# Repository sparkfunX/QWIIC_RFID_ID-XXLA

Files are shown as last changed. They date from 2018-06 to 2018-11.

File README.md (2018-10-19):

SparkX Qwiic RFID ID-XXLA
========================================

SparkX Qwiic RFID 

[*SparX Qwiic RFID (SPX-14867)*](https://www.sparkfun.com/products/14867)

The Qwiic RFID ID-XXLA is a simple board that pairs with the ID-3LA, ID-12LA, ID-20LA, RFID modules. Included with the product is the ID-12LA and three RFID 125Khz cards as a full kit to get you started integrating an I2C RFID solution into your project. Utilizing the onboard ATtiny84A, the Qwiic RFID takes the six byte ID tag of your 125Khz RFID card, attaches a time stamp to it, and puts it onto a stack that holds up to 20 unique RFID scans at any given time. This information is easy to get at with some simple I2C commands and we’ve included some example code that shows you just how to do it using the broken out interrupt pin. We’ve also broken out two antennae pins that should only be used with the smaller ID-3LA.

The Qwiic RFID has a buzzer and LED that indicates that card has been scanned. We’ve included a jumper to disconnect the buzzer, a jumper for the I2C pull-up resistors, an interrupt jumper, and finally an address jumper. The Qwiic RFID comes fully decked out in Qwiic connectors, no need to solder a thing, just plug it in and start scanning!

We do not plan to regularly produce SparkX products so get them while they’re hot!

Repository Contents
-------------------

* **/Examples** - A number of examples to show how to read buttons with time, change the I2C address and scan for I2C devices
* **/Firmware** - The core sketch that runs Qwiic RFID ID-XXLA
* **/Hardware** - Eagle design files (.brd, .sch)

License Information
-------------------

This product is _**open source**_! 

Please review the LICENSE.md file for license information. 

If you have any questions or concerns on licensing, please contact techsupport@sparkfun.com.

Please use, reuse, and modify these files as you see fit. Please maintain attribution to SparkFun Electronics and release any derivative under the same license.

Distributed as-is; no warranty is given.

- Your friends at SparkFun.

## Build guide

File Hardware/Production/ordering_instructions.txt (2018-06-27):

panel size, 91x107mm
PCB thickness, 1.6mm
number of layers, 2
soldermask color, Black
silkscreen color, White
oz copper, 1oz
finish, HASL lead free
stencils, top+bottom
pcs per panel, 9

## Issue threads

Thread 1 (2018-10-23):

Problem reading using an ESP32Thing

f34rdotcom, 2018-10-23:
I have been unable to read back from the device. I have multiple devices on an i2c bus and other devices do read so I am leaning towards an issue in this firmware not being compatible with esp-idf i2c driver.

When I write to its address 0x7d it does report an ACK that and so my i2c scanner does detect the device successfully. If however I try and read by 10 bytes from the device it end up with a timeout from the i2c driver on the esp32. It also seems to take a long time for the ATINY to ACK the address byte when reading. If I write to the address the ATINY does not delay the ACK.

I have disabled PULL UP's on all the devices on my i2c bus and turn on pullup on the GPIO pins on the ESP32

It is not clear what firmware is on the QWIIC_RFID_ID but it was within the past few weeks purchased from sparkfun.

Any help/suggestions appreciated.

```
i2c_config_t conf;
conf.mode = I2C_MODE_MASTER;
conf.sda_io_num = GPIO_NUM_4;
conf.scl_io_num = GPIO_NUM_2;
conf.sda_pullup_en = GPIO_PULLUP_ENABLE;
conf.scl_pullup_en = GPIO_PULLUP_ENABLE;
conf.master.clk_speed = speed;
ESP_ERROR_CHECK(i2c_param_config(I2C_NUM_0, &conf));
ESP_ERROR_CHECK(i2c_driver_install(I2C_NUM_0, I2C_MODE_MASTER, 0, 0, 0));

uint8_t temp[32];
i2c_cmd_handle_t cmd = i2c_cmd_link_create();
i2c_master_start(cmd);
i2c_master_write_byte(cmd, (0x7d << 1) | I2C_MASTER_READ, true);
ESP_ERROR_CHECK(i2c_master_read(cmd, temp, 9, ACK_VAL));
ESP_ERROR_CHECK(i2c_master_read_byte(cmd, temp+9, NACK_VAL));
i2c_master_stop(cmd);
espRc = i2c_master_cmd_begin(I2C_NUM_0, cmd, 100/portTICK_PERIOD_MS);
if (espRc == ESP_OK) {
  printf("OK);
} else {
  printf("FAIL");
}
i2c_cmd_link_delete(cmd);

```
The resulting capture.
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

edspark, 2018-10-24:
Hmmm...nothing comes to mind off the top of my head. I'll take a gander at this today and hopefully find an answer for you.

edspark, 2018-10-24:
I hooked up my a Sparkfun ESP32 Thing to my Qwiic RFID and was able to read back from two separate tags using pins 21/22 as SDA/SCL respectively with no other devices attached:
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

My first thought is that there's some sort of cold joint on the UART pin from the RFID reader to the product. I did however test each one of the boards personally, but it is possible that something got bumped in transit or through use.  Below is an image of the header for the RFID module with the pad for the UART pin circled in blue(pin 9):
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

Let me know if there's anything else I can help with.

f34rdotcom, 2018-10-24:
The problem I am seeing is on the i2c bus portion from the ATTINY85 chip not the UART pins. As best I can describe the ATTINY85 is not pulling down the SDA line after the 8th bit to indicate it received the READ command with address.

f34rdotcom, 2018-11-01:
Just an update.

I am able to read the bytes using an ESP32Thing provided I set the i2c timeout after installing the i2c driver. The default value is 6400.
  `i2c_set_timeout(I2C_NUM_0, 32000);`

This fixes the "clock stretching" that is happening from the ATTINY85 board. I am however still see many random bad responses with NAK errors and AFAIK I have no way of detecting if a message had NAK errors. I end up with a successful read but the data is full of 0xff bytes. These issues seem very specific to esp-idf so I am going to close this. If you have some ability to help me confirm and help determine how to fix this any help would be appreciated.

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

RFID:80ffffffffffffffffff
I (5539912) MYI2CSENS: myi2c-rfid 4294967295,42949672
RFID:000000000000000001c1
I (5540412) MYI2CSENS: myi2c-rfid 449,0
RFID:000000000000000001c1
I (5540912) MYI2CSENS: myi2c-rfid 449,0
RFID:000000000000000001c1
I (5541412) MYI2CSENS: myi2c-rfid 449,0
RFID:000000000000000001c1
I (5541912) MYI2CSENS: myi2c-rfid 449,0
RFID:0000000000007fffffff
I (5542412) MYI2CSENS: myi2c-rfid 2147483647,0

edspark, 2018-11-30:
I'm going to close this for now @f34rdotcom. If you discover something please feel free to open it back up.

Closed 2018-11-30.

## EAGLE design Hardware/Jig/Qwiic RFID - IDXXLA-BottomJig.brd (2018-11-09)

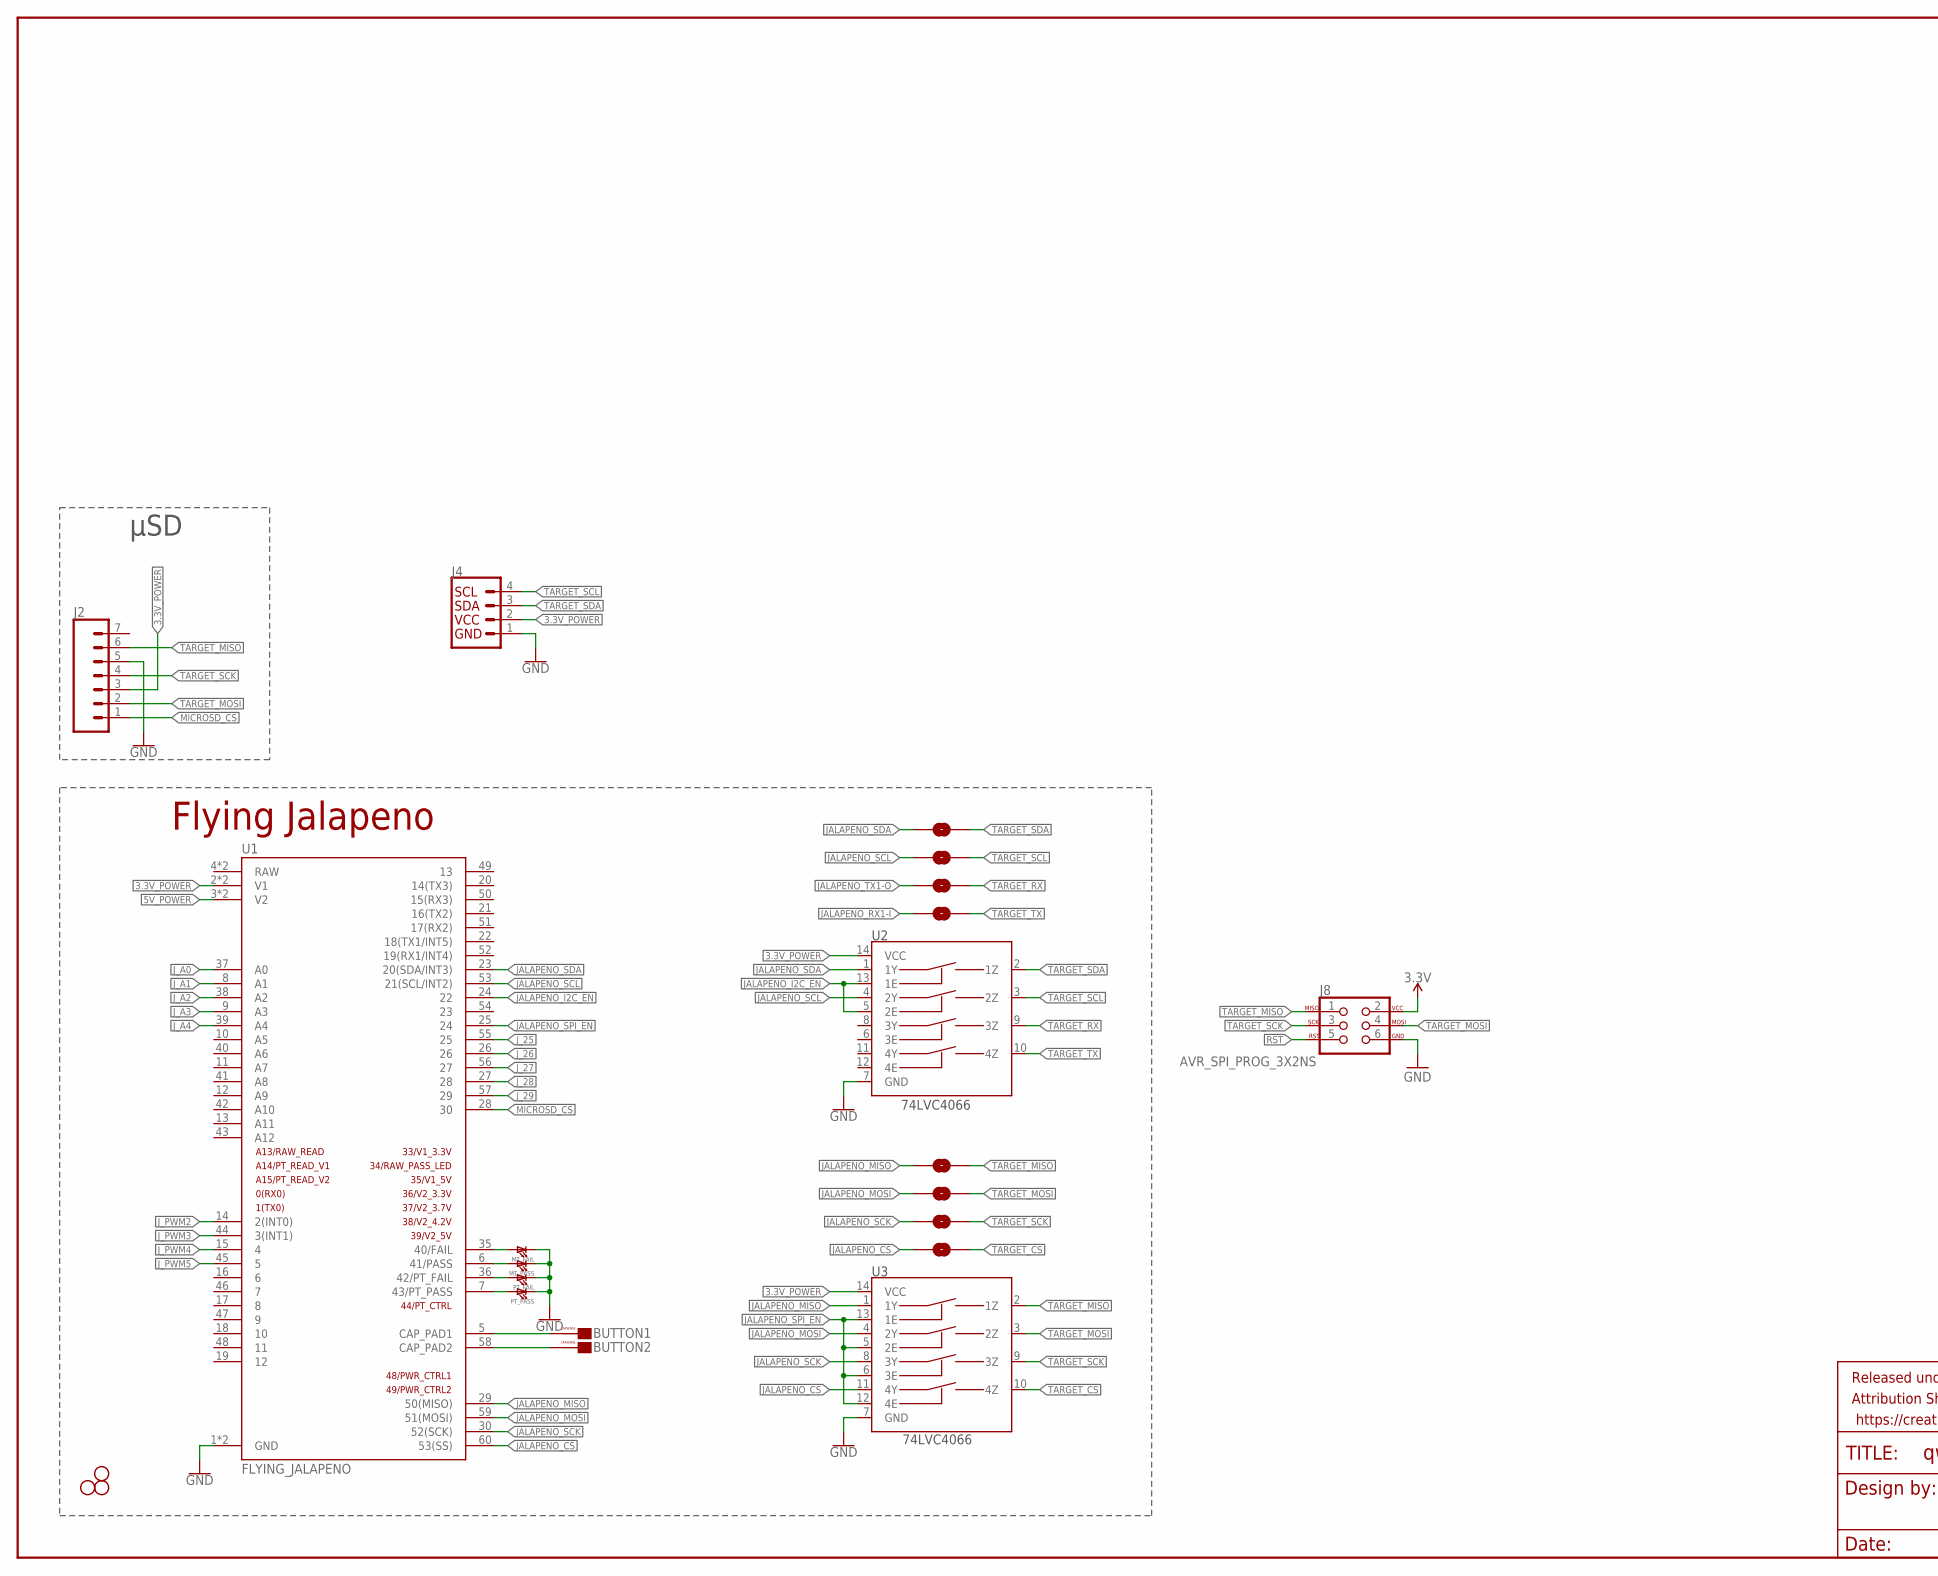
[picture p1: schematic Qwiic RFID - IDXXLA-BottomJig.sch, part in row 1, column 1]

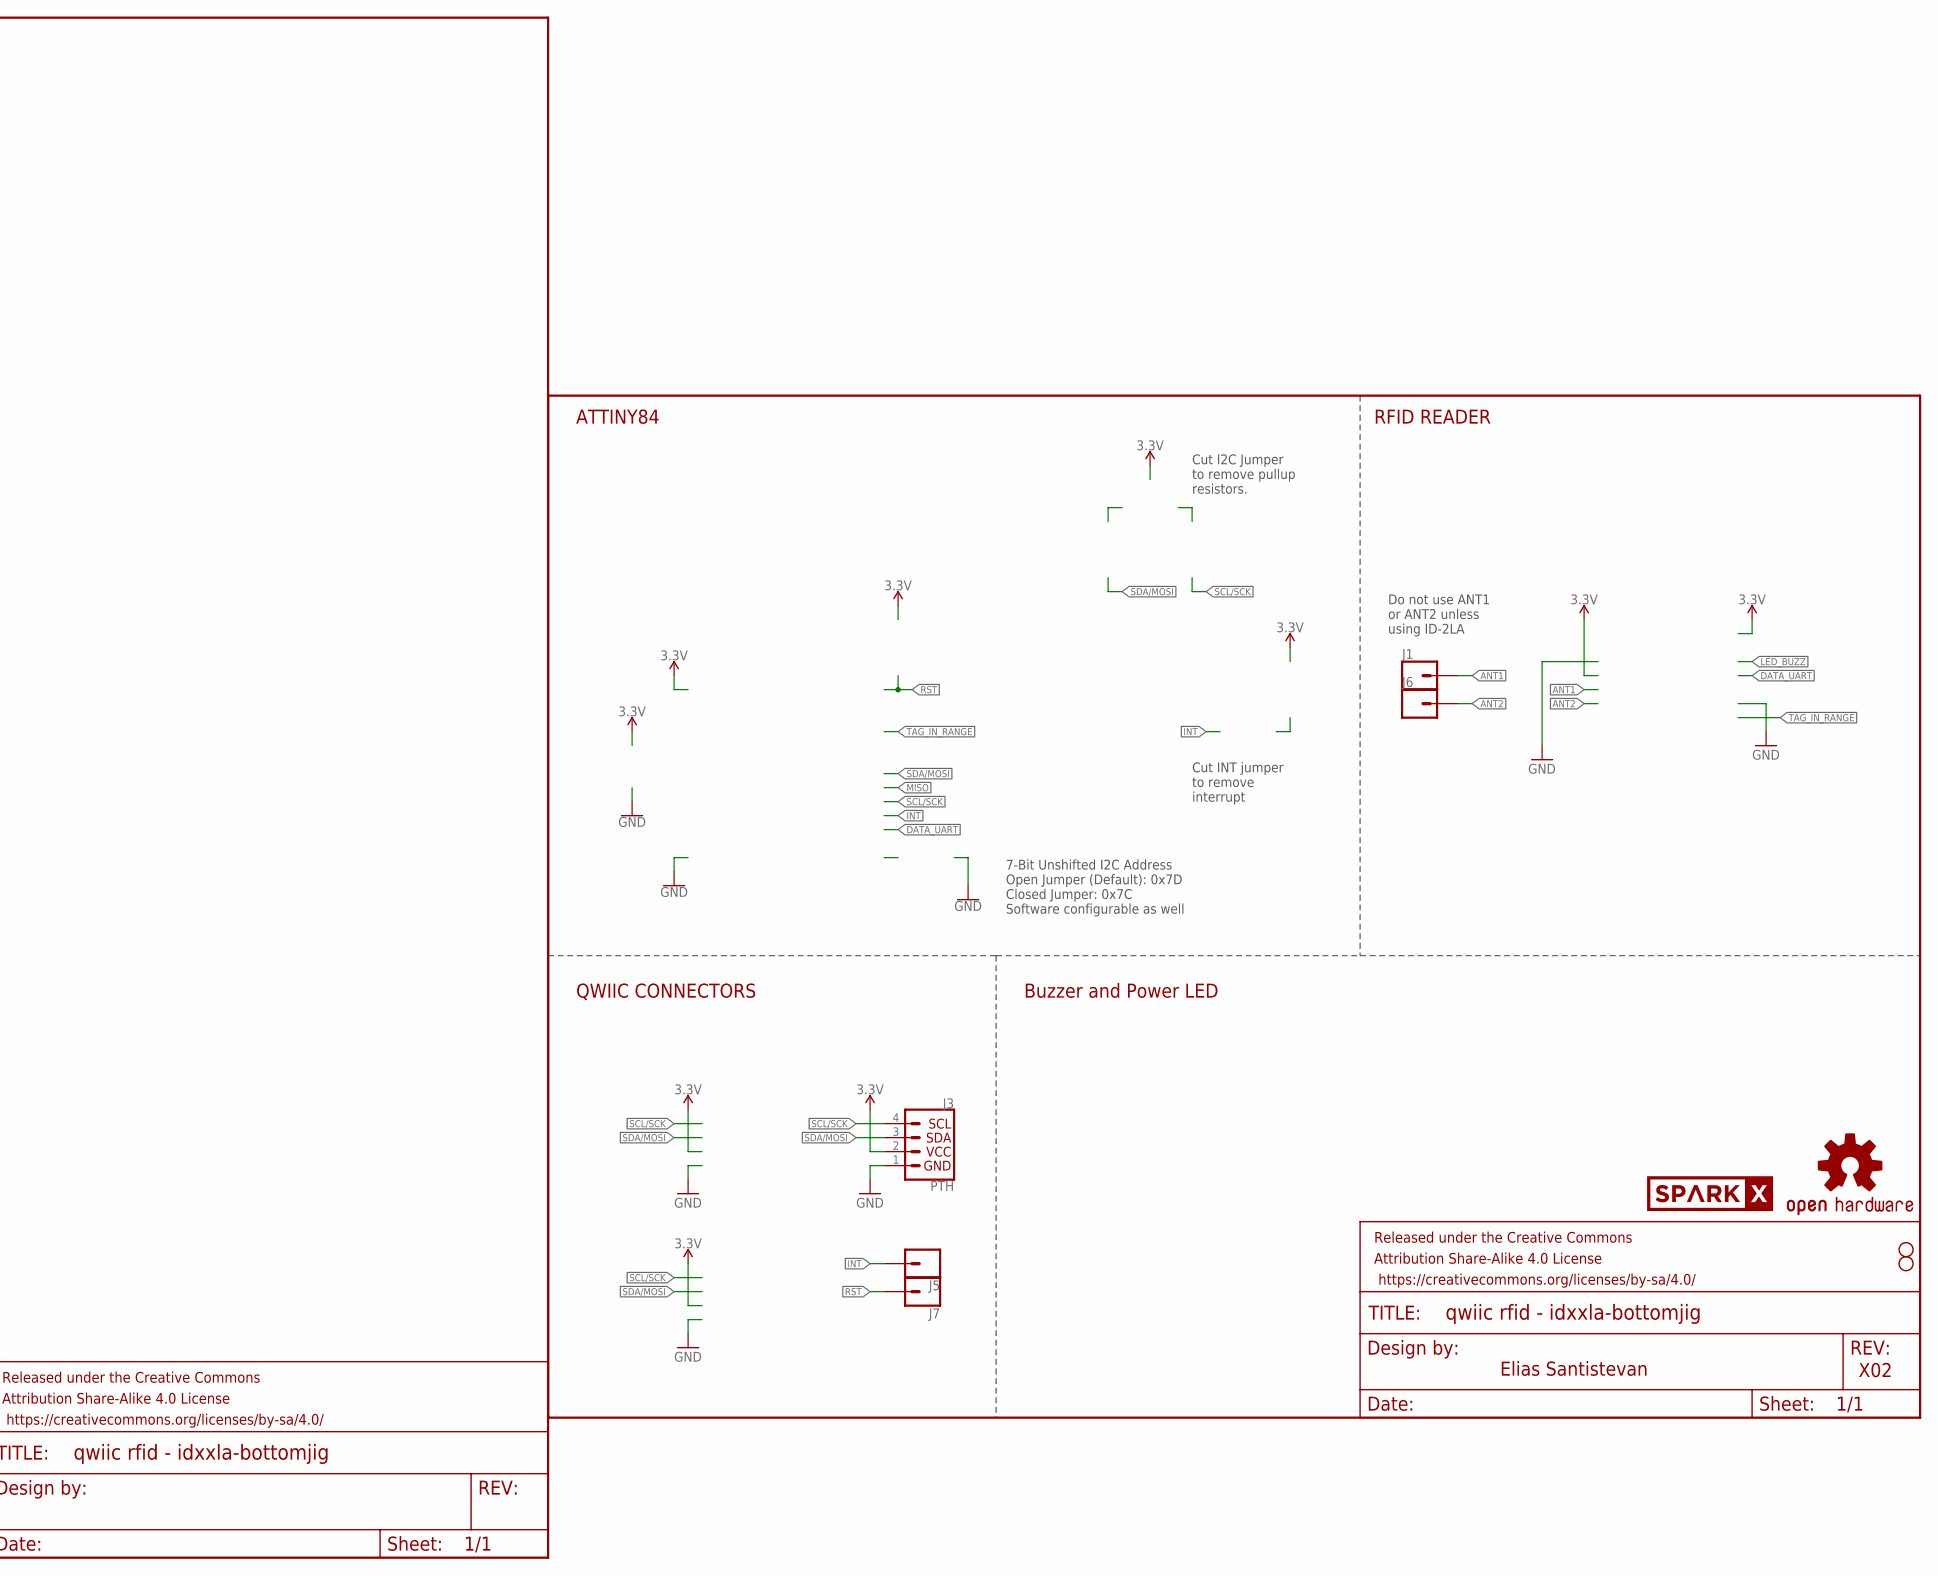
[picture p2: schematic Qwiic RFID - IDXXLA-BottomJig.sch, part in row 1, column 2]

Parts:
BUTTON1, BUTTON2: CAPSENSE_BUTTON_PAD_ONLY; CAPSENSE_BUTTON_PADS_ONLY
FRAME1: FRAME-LETTER; CREATIVE_COMMONS
FRAME2: FRAME-LEDGER; CREATIVE_COMMONS
H1, H3, H4: STAND-OFF
J1, J5, J6, J7: CONN_01PTH_NO_SILK_YES_STOP; 1X01_NO_SILK
J2: CONN_07; 1X07
J3: PTH; 1X04_NO_SILK
J4: QWIIC_CONNECTORJS-1MM; 1X04_1MM_RA
J8: AVR_SPI_PROG_3X2NS; 2X3-NS
JP3, JP4: STAND-OFF
J_SCL, J_SCL1, J_SCL2, J_SCL3, J_SCL4, J_SCL5: JUMPER-SMT_2_NO_NO-SILK; SMT-JUMPER_2_NO_NO-SILK
J_SDA, J_SDA1: JUMPER-SMT_2_NO_NO-SILK; SMT-JUMPER_2_NO_NO-SILK
LOGO1: OSHW-LOGOMINI; OSHW-LOGO-MINI
MT_FAIL: LED1206; LED-1206
MT_PASS: LED1206; LED-1206
PT_FAIL: LED1206; LED-1206
PT_PASS: LED1206; LED-1206
U1: FLYING_JALAPENO; FLYING_JALAPENO_V3_M
U2, U3: 74LVC4066; SO14
U$4: SPARKX-LOGO3; SPARKX-SMALL

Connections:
3.3V: J3.2 (VCC), J8.2
3.3V_POWER: J2.3, J4.2, U1.2 (V1), U1.32 (V1), U2.14 (VCC), U3.14 (VCC)
5V_POWER: U1.3 (V2), U1.33 (V2)
!INT: J5.1
!RST: J7.1, J8.5
ANT1: J1.1
ANT2: J6.1
BUTTON1: BUTTON1.CAPSENSE_PAD, U1.5 (CAP_PAD1)
BUTTON2: BUTTON2.CAPSENSE_PAD, U1.58 (CAP_PAD2)
GND: J2.5, J3.1 (GND), J4.1, J8.6, MT_FAIL.C, MT_PASS.C, PT_FAIL.C, PT_PASS.C, U1.1 (GND), U1.31 (GND), U2.7 (GND), U3.7 (GND)
JALAPENO_CS: J_SDA1.1, U1.60 (53(SS)), U3.11 (4Y)
JALAPENO_I2C_EN: U1.24 (22), U2.5 (2E), U2.13 (1E)
JALAPENO_MISO: J_SCL5.1, U1.29 (50(MISO)), U3.1 (1Y)
JALAPENO_MOSI: J_SCL3.1, U1.59 (51(MOSI)), U3.4 (2Y)
JALAPENO_RX1-I: J_SDA.1
JALAPENO_SCK: J_SCL4.1, U1.30 (52(SCK)), U3.8 (3Y)
JALAPENO_SCL: J_SCL.1, U1.53 (21(SCL/INT2)), U2.4 (2Y)
JALAPENO_SDA: J_SCL2.1, U1.23 (20(SDA/INT3)), U2.1 (1Y)
JALAPENO_SPI_EN: U1.25 (24), U3.5 (2E), U3.6 (3E), U3.12 (4E), U3.13 (1E)
JALAPENO_TX1-O: J_SCL1.1
J_25: U1.55 (25)
J_26: U1.26
J_27: U1.56 (27)
J_28: U1.27 (28)
J_29: U1.57 (29)
J_A0: U1.37 (A0)
J_A1: U1.8 (A1)
J_A2: U1.38 (A2)
J_A3: U1.9 (A3)
J_A4: U1.39 (A4)
J_PWM2: U1.14 (2(INT0))
J_PWM3: U1.44 (3(INT1))
J_PWM4: U1.15 (4)
J_PWM5: U1.45 (5)
MICROSD_!CS!: J2.1, U1.28 (30)
MT_FAIL: MT_FAIL.A, U1.35 (40/FAIL)
MT_PASS: MT_PASS.A, U1.6 (41/PASS)
PT_FAIL: PT_FAIL.A, U1.36 (42/PT_FAIL)
PT_PASS: PT_PASS.A, U1.7 (43/PT_PASS)
SCL/SCK: J3.4 (SCL)
SDA/MOSI: J3.3 (SDA)
TARGET_CS: J_SDA1.2, U3.10 (4Z)
TARGET_MISO: J2.6, J8.1, J_SCL5.2, U3.2 (1Z)
TARGET_MOSI: J2.2, J8.4, J_SCL3.2, U3.3 (2Z)
TARGET_RX: J_SCL1.2, U2.9 (3Z)
TARGET_SCK: J2.4, J8.3, J_SCL4.2, U3.9 (3Z)
TARGET_SCL: J4.4, J_SCL.2, U2.3 (2Z)
TARGET_SDA: J4.3, J_SCL2.2, U2.2 (1Z)
TARGET_TX: J_SDA.2, U2.10 (4Z)

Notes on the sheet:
X02
Buzzer and Power LED
RFID READER
ATTINY84
QWIIC CONNECTORS
Elias Santistevan
7-Bit Unshifted I2C Address Open Jumper (Default): 0x7D Closed Jumper: 0x7C Software configurable as well
Cut INT jumper to remove interrupt
Cut I2C Jumper to remove pullup resistors.
Do not use ANT1 or ANT2 unless using ID-2LA
Flying Jalapeno
μSD

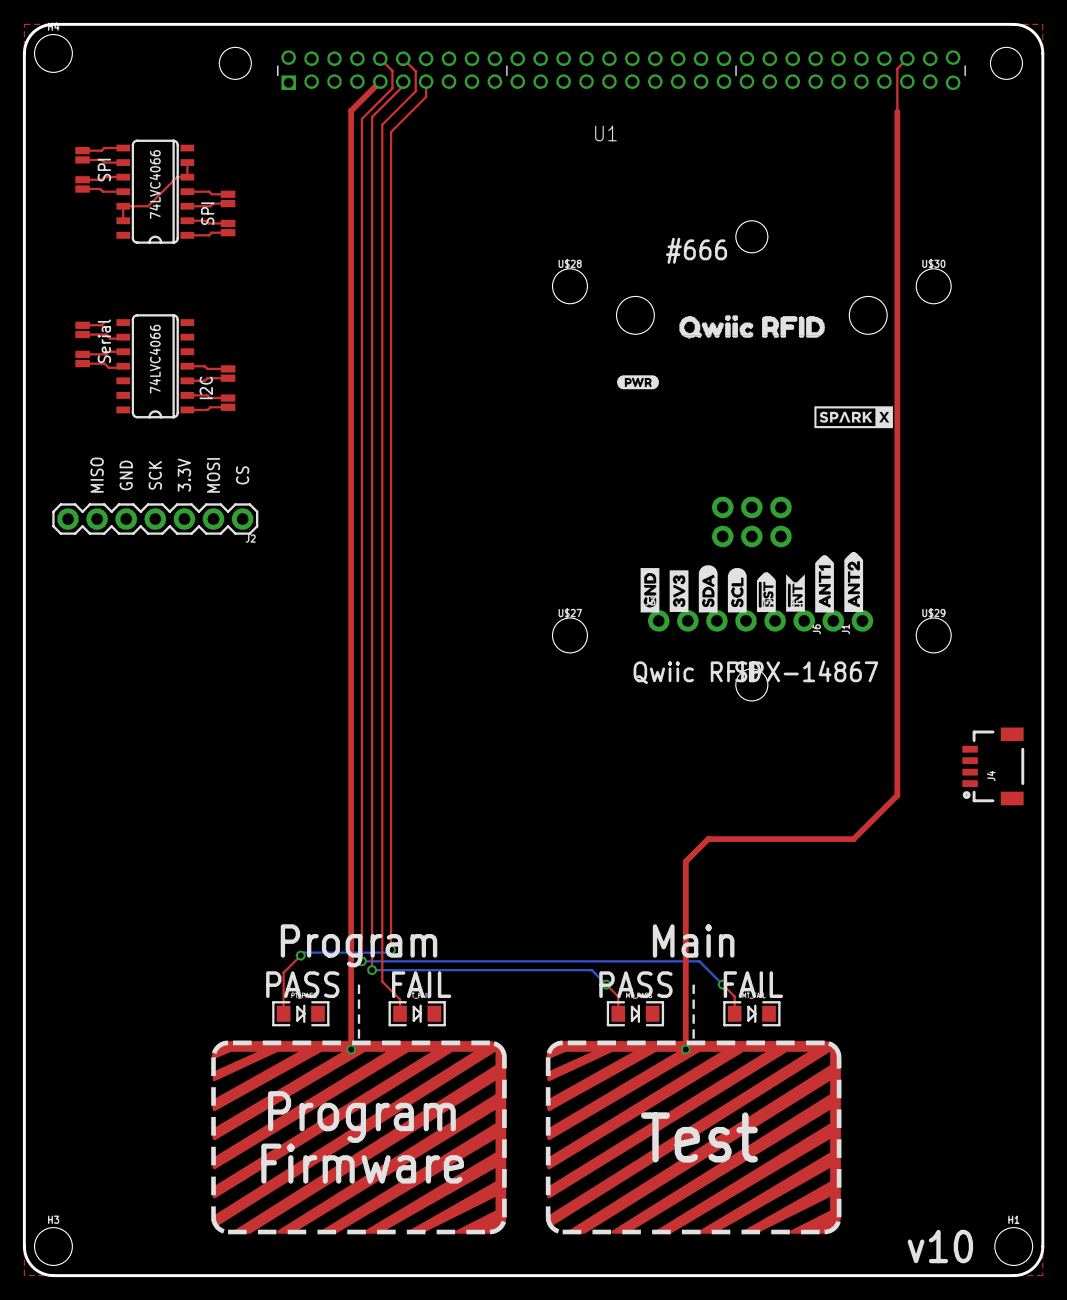
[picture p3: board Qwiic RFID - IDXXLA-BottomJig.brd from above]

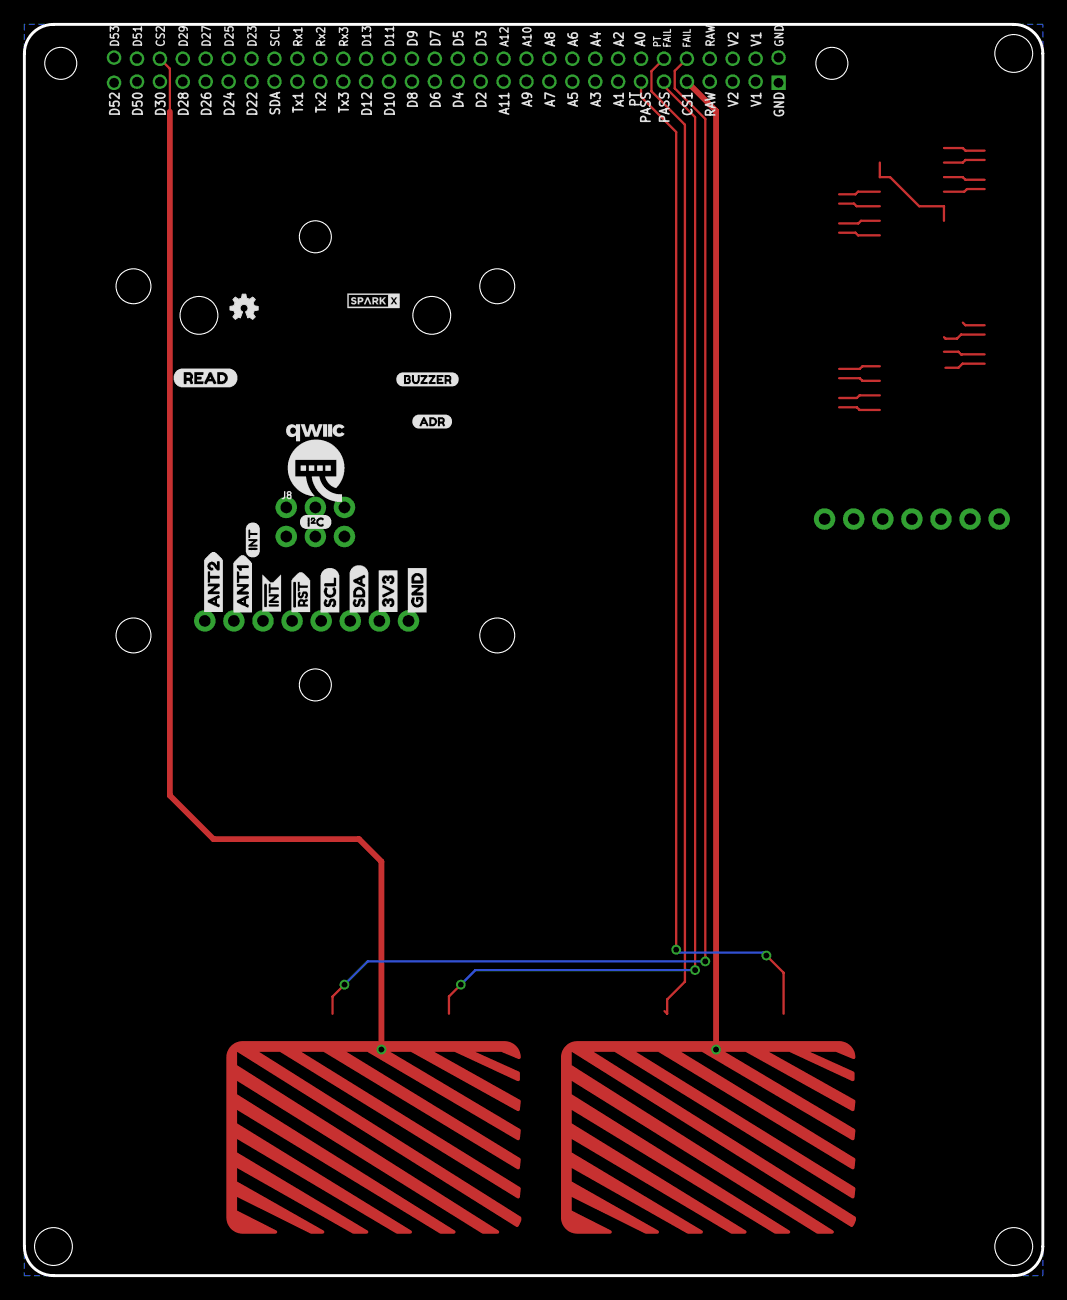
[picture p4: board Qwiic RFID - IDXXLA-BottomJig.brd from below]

Board: 2 copper layers, 88.9 x 109.2 mm, 65 parts (17 on the bottom side), 28 nets.

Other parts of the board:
U$1: SPARKX-TINY
U$2: I_SUPER2_C-()-03
U$3, U$17: ANT20
U$5, U$26: RST#-[>
U$6, U$23: SDA-[)
U$7, U$22: SCL-[)
U$8: QWIIC-LOGO-MEDIUM
U$9, U$25: GND-04
U$10, U$24: 3V3-04
U$11, U$21: INT#-[<
U$12: ADR0
U$13: INT0
U$14: PWR-()-03
U$15: BUZZER0
U$16, U$20: ANT10
U$18: READ0
U$19: QWIIC_RFID0
U$27, U$28, U$29, U$30: STAND-OFF-TIGHT
U$31, U$32: NUBBIN_LOCKER

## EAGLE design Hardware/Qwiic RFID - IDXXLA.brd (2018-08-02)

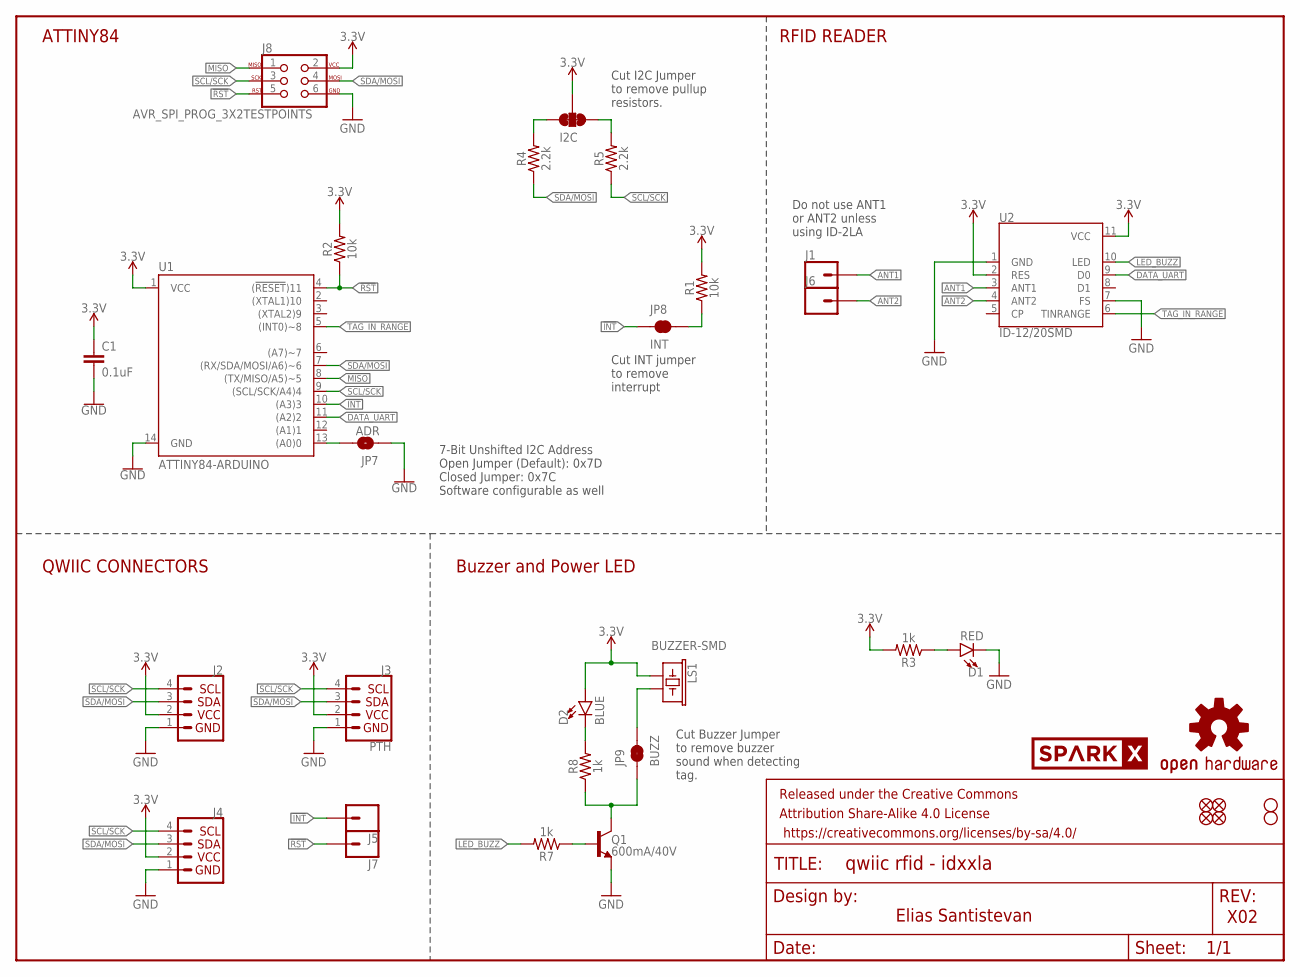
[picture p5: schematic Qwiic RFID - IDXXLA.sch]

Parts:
C1: 0.1uF; 0603
D1: RED; LED-0603
D2: BLUE; LED-0603
FRAME1: FRAME-LETTER; CREATIVE_COMMONS
I2C: JUMPER-SMT_3_2-NC_TRACE_SILK; SMT-JUMPER_3_2-NC_TRACE_SILK
J1, J5, J6, J7: CONN_01PTH_NO_SILK_YES_STOP; 1X01_NO_SILK
J2, J4: QWIIC_CONNECTORJS-1MM; 1X04_1MM_RA
J3: PTH; 1X04_NO_SILK
J8: AVR_SPI_PROG_3X2TESTPOINTS; 2X3_TEST_POINTS
JP1, JP2, JP5, JP6: FIDUCIALUFIDUCIAL; MICRO-FIDUCIAL
JP3, JP4: STAND-OFF
JP7: ADR; SMT-JUMPER_2_NO_SILK
JP8: INT; SMT-JUMPER_2_NC_TRACE_SILK
JP9: BUZZ; SMT-JUMPER_2_NC_TRACE_SILK
LOGO1: OSHW-LOGOMINI; OSHW-LOGO-MINI
LS1: BUZZER-SMD; BUZZER-CCV
Q1: 600mA/40V; SOT23-3
R1, R2: 10k; 0603
R3, R7, R8: 1k; 0603
R4, R5: 2.2k; 0603
U1: ATTINY84-ARDUINO; SO14
U2: ID-12/20SMD; ID-12_SMD
U$4: SPARKX-LOGO3; SPARKX-SMALL

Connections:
3.3V: C1.1, D2.A, I2C.2, J2.2, J3.2 (VCC), J4.2, J8.2, LS1.+ (1), R1.2, R2.2, R3.2, U1.1 (VCC), U2.2 (RES), U2.11 (VCC)
!INT: J5.1, JP8.1, U1.10 ((A3)3)
!RST: J7.1, J8.5, R2.1, U1.4 ((!RESET!)11)
ANT1: J1.1, U2.3 (ANT1)
ANT2: J6.1, U2.4 (ANT2)
DATA_UART: U1.11 ((A2)2), U2.9 (D0)
GND: C1.2, D1.C, J2.1, J3.1 (GND), J4.1, J8.6, JP7.1, Q1.2 (E), U1.14 (GND), U2.1 (GND), U2.7 (FS)
LED_BUZZ: R7.2, U2.10 (LED)
MISO: J8.1, U1.8 ((TX/MISO/A5)~5)
unnamed: I2C.1, R5.2
unnamed: I2C.3, R4.2
unnamed: D1.A, R3.1
unnamed: JP8.2, R1.1
unnamed: D2.C, R8.2
unnamed: JP7.2, U1.13 ((A0)0)
unnamed: Q1.1 (B), R7.1
unnamed: JP9.1, Q1.3 (C), R8.1
unnamed: JP9.2, LS1.- (2)
SCL/SCK: J2.4, J3.4 (SCL), J4.4, J8.3, R5.1, U1.9 ((SCL/SCK/A4)4)
SDA/MOSI: J2.3, J3.3 (SDA), J4.3, J8.4, R4.1, U1.7 ((RX/SDA/MOSI/A6)~6)
TAG_IN_RANGE: U1.5 ((INT0)~8), U2.6 (TINRANGE)

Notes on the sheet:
X02
Buzzer and Power LED
RFID READER
ATTINY84
QWIIC CONNECTORS
Elias Santistevan
7-Bit Unshifted I2C Address Open Jumper (Default): 0x7D Closed Jumper: 0x7C Software configurable as well
Cut Buzzer Jumper to remove buzzer sound when detecting tag.
Cut INT jumper to remove interrupt
Cut I2C Jumper to remove pullup resistors.
Do not use ANT1 or ANT2 unless using ID-2LA

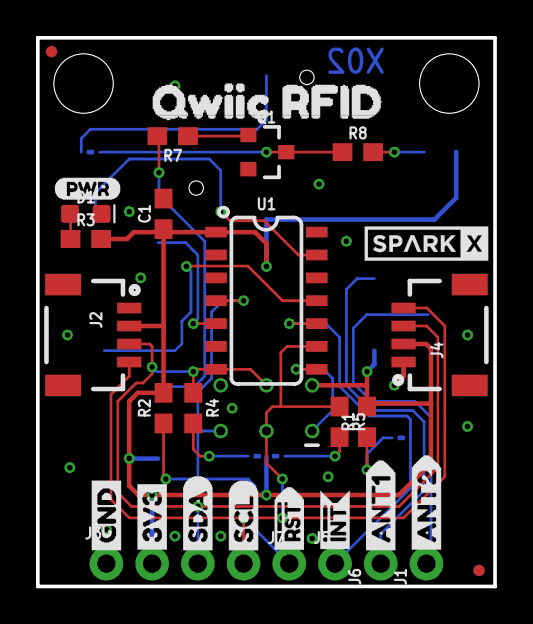
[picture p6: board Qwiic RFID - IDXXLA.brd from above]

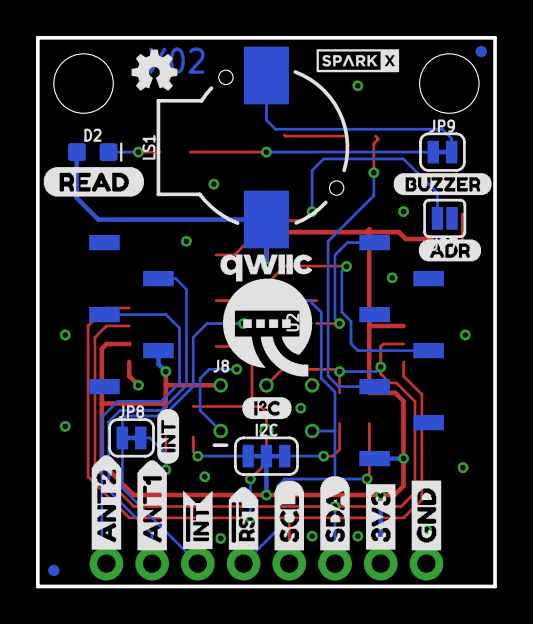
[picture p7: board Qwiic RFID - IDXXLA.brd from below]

Board: 2 copper layers, 25.4 x 30.5 mm, 60 parts (26 on the bottom side), 21 nets.

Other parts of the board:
U$1: SPARKX-TINY
U$2: I_SUPER2_C-()-03
U$3, U$17: ANT20
U$5, U$26: RST#-[>
U$6, U$23: SDA-[)
U$7, U$22: SCL-[)
U$8: QWIIC-LOGO-MEDIUM
U$9, U$25: GND-04
U$10, U$24: 3V3-04
U$11, U$21: INT#-[<
U$12: ADR0
U$13: INT0
U$14: PWR-()-03
U$15: BUZZER0
U$16, U$20: ANT10
U$18: READ0
U$19: QWIIC_RFID0

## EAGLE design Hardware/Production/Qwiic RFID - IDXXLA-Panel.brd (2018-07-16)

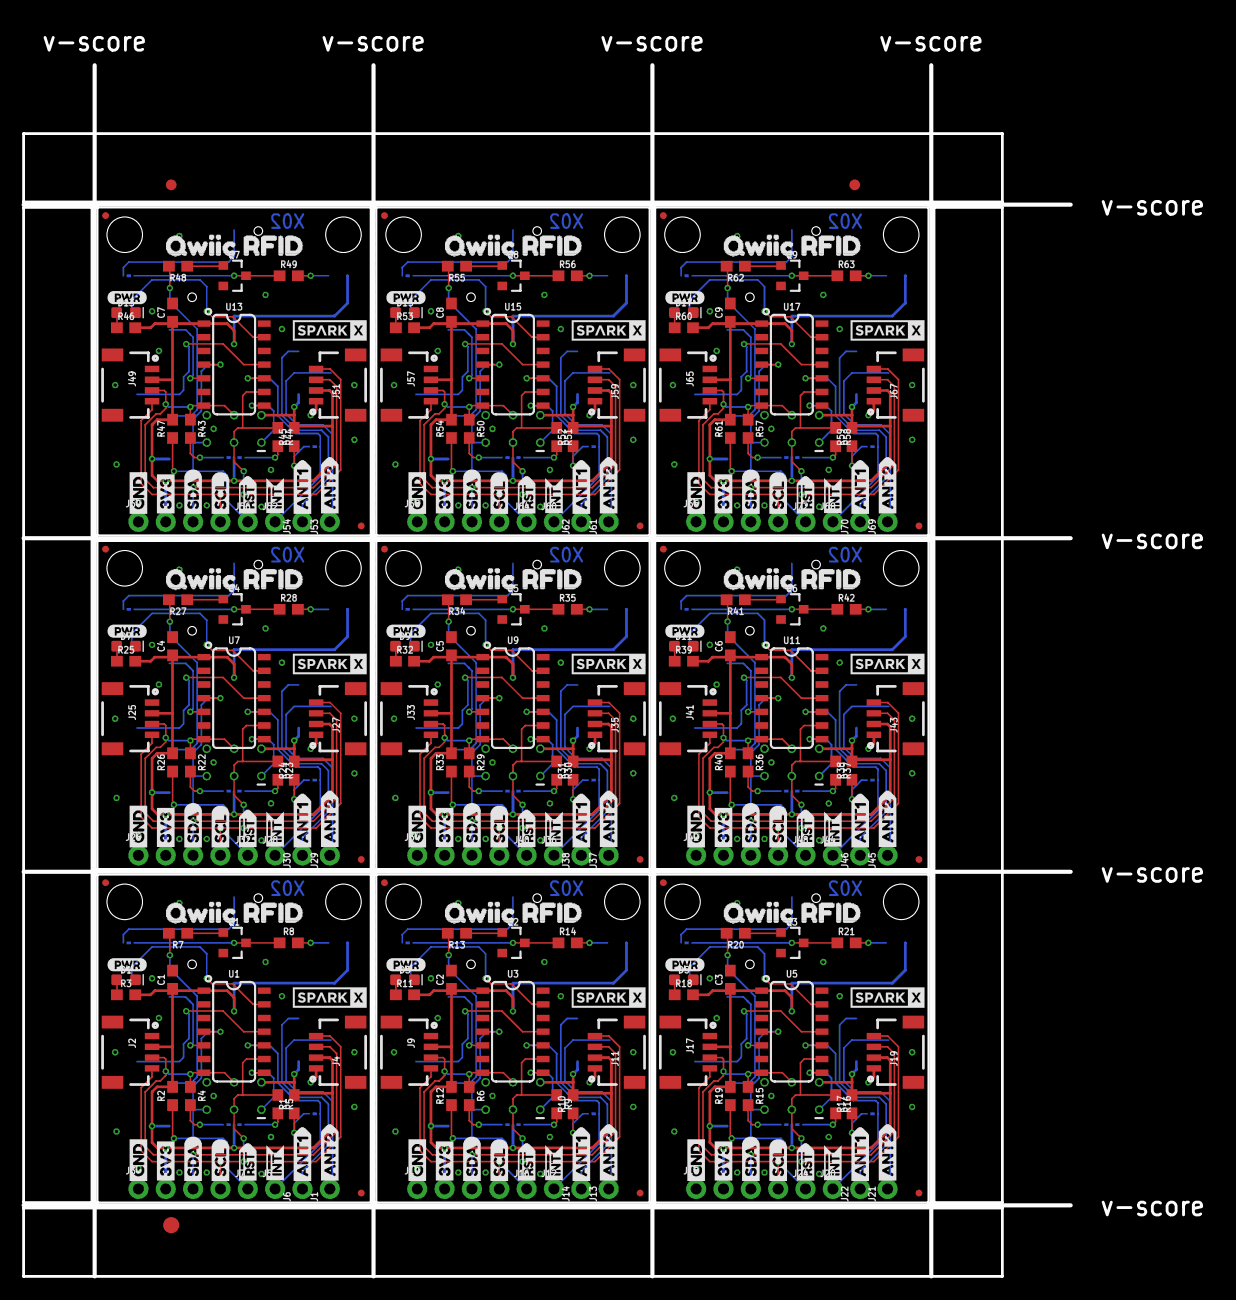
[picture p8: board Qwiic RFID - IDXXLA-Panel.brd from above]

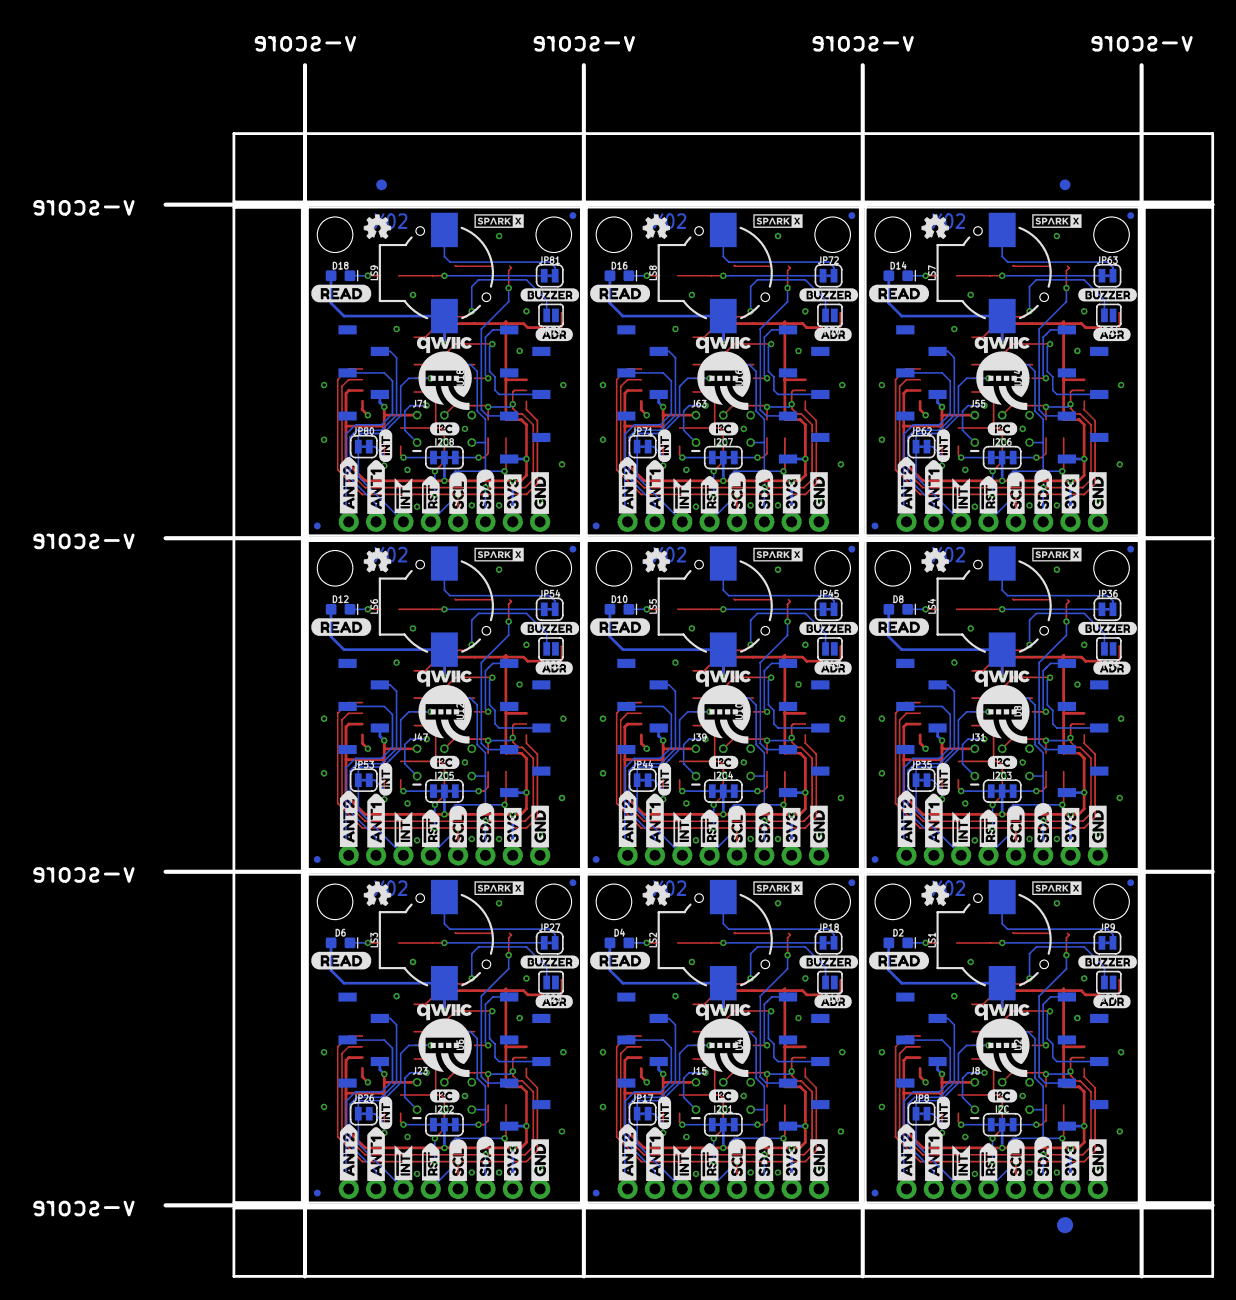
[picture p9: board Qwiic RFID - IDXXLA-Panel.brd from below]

Board: 2 copper layers, 97.3 x 112.5 mm, 537 parts (237 on the bottom side), 189 nets.

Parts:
C1, C2, C3, C4, C5, C6, C7, C8, C9: 0.1uF; 0603
D1, D3, D5, D7, D9, D11, D13, D15, D17: RED; LED-0603
D2, D4, D6, D8, D10, D12, D14, D16, D18: BLUE; LED-0603
E$1, E$2, E$3, E$4: FIDUCIAL-1X2
E$5, E$6: FIDUCIAL-1.5X3
I2C, I2C1, I2C2, I2C3, I2C4, I2C5, I2C6, I2C7, I2C8: SMT-JUMPER_3_2-NC_TRACE_SILK
J1, J5, J6, J7, J12, J13, J14, J16, J20, J21, J22, J24, J28, J29, J30, J32, J36, J37, J38, J40, J44, J45, J46, J48, J52, J53, J54, J56, J60, J61, J62, J64, J68, J69, J70, J72: 1X01_NO_SILK
J2, J4, J9, J11, J17, J19, J25, J27, J33, J35, J41, J43, J49, J51, J57, J59, J65, J67: SMD; 1X04_1MM_RA
J3, J10, J18, J26, J34, J42, J50, J58, J66: PTH; 1X04_NO_SILK
J8, J15, J23, J31, J39, J47, J55, J63, J71: AVR_SPI_PROG_3X2TESTPOINTS; 2X3_TEST_POINTS
JP1, JP2, JP5, JP6, JP12, JP13, JP14, JP15, JP21, JP22, JP23, JP24, JP30, JP31, JP32, JP33, JP39, JP40, JP41, JP42, JP48, JP49, JP50, JP51, JP57, JP58, JP59, JP60, JP66, JP67, JP68, JP69, JP75, JP76, JP77, JP78: FIDUCIALUFIDUCIAL; MICRO-FIDUCIAL
JP3, JP4, JP10, JP11, JP19, JP20, JP28, JP29, JP37, JP38, JP46, JP47, JP55, JP56, JP64, JP65, JP73, JP74: STAND-OFF
JP7, JP16, JP25, JP34, JP43, JP52, JP61, JP70, JP79: ADR; SMT-JUMPER_2_NO_SILK
JP8, JP17, JP26, JP35, JP44, JP53, JP62, JP71, JP80: INT; SMT-JUMPER_2_NC_TRACE_SILK
JP9, JP18, JP27, JP36, JP45, JP54, JP63, JP72, JP81: BUZZ; SMT-JUMPER_2_NC_TRACE_SILK
LOGO1, LOGO2, LOGO3, LOGO4, LOGO5, LOGO6, LOGO7, LOGO8, LOGO9: OSHW-LOGOMINI; OSHW-LOGO-MINI
LS1, LS2, LS3, LS4, LS5, LS6, LS7, LS8, LS9: BUZZER-SMD; BUZZER-CCV
Q1, Q2, Q3, Q4, Q5, Q6, Q7, Q8, Q9: 600mA/40V; SOT23-3
R1, R2, R10, R12, R17, R19, R24, R26, R31, R33, R38, R40, R45, R47, R52, R54, R59, R61: 10k; 0603
R3, R7, R8, R11, R13, R14, R18, R20, R21, R25, R27, R28, R32, R34, R35, R39, R41, R42, R46, R48, R49, R53, R55, R56, R60, R62, R63: 1k; 0603
R4, R5, R6, R9, R15, R16, R22, R23, R29, R30, R36, R37, R43, R44, R50, R51, R57, R58: 2.2k; 0603
U1, U3, U5, U7, U9, U11, U13, U15, U17: ATTINY84-ARDUINO; SO14
U2, U4, U6, U8, U10, U12, U14, U16, U18: ID-12/20SMD; ID-12_SMD
U$1, U$52, U$78, U$104, U$130, U$156, U$182, U$208, U$234: SPARKX-TINY
U$2, U$48, U$74, U$100, U$126, U$152, U$178, U$204, U$230: I_SUPER2_C-()-03
U$3, U$17, U$37, U$40, U$63, U$66, U$89, U$92, U$115, U$118, U$141, U$144, U$167, U$170, U$193, U$196, U$219, U$222: ANT20
U$4, U$28, U$54, U$80, U$106, U$132, U$158, U$184, U$210: SPARKX-LOGO3; SPARKX-SMALL
U$5, U$26, U$29, U$47, U$55, U$73, U$81, U$99, U$107, U$125, U$133, U$151, U$159, U$177, U$185, U$203, U$211, U$229: RST#-[>
U$6, U$23, U$30, U$44, U$56, U$70, U$82, U$96, U$108, U$122, U$134, U$148, U$160, U$174, U$186, U$200, U$212, U$226: SDA-[)
U$7, U$22, U$31, U$43, U$57, U$69, U$83, U$95, U$109, U$121, U$135, U$147, U$161, U$173, U$187, U$199, U$213, U$225: SCL-[)
U$8, U$27, U$53, U$79, U$105, U$131, U$157, U$183, U$209: QWIIC-LOGO-MEDIUM
U$9, U$25, U$32, U$46, U$58, U$72, U$84, U$98, U$110, U$124, U$136, U$150, U$162, U$176, U$188, U$202, U$214, U$228: GND-04
U$10, U$24, U$33, U$45, U$59, U$71, U$85, U$97, U$111, U$123, U$137, U$149, U$163, U$175, U$189, U$201, U$215, U$227: 3V3-04
U$11, U$21, U$34, U$42, U$60, U$68, U$86, U$94, U$112, U$120, U$138, U$146, U$164, U$172, U$190, U$198, U$216, U$224: INT#-[<
U$12, U$49, U$75, U$101, U$127, U$153, U$179, U$205, U$231: ADR0
U$13, U$50, U$76, U$102, U$128, U$154, U$180, U$206, U$232: INT0
U$14, U$51, U$77, U$103, U$129, U$155, U$181, U$207, U$233: PWR-()-03
U$15, U$35, U$61, U$87, U$113, U$139, U$165, U$191, U$217: BUZZER0
U$16, U$20, U$36, U$41, U$62, U$67, U$88, U$93, U$114, U$119, U$140, U$145, U$166, U$171, U$192, U$197, U$218, U$223: ANT10
U$18, U$38, U$64, U$90, U$116, U$142, U$168, U$194, U$220: READ0
U$19, U$39, U$65, U$91, U$117, U$143, U$169, U$195, U$221: QWIIC_RFID0

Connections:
3.3V: C1.1, D2.A, I2C.2, J2.2, J3.2, J4.2, J8.2, LS1.+, R1.2, R2.2, R3.2, U1.1, U2.2, U2.11
3.3V1: C2.1, D4.A, I2C1.2, J9.2, J10.2, J11.2, J15.2, LS2.+, R10.2, R11.2, R12.2, U3.1, U4.2, U4.11
3.3V2: C3.1, D6.A, I2C2.2, J17.2, J18.2, J19.2, J23.2, LS3.+, R17.2, R18.2, R19.2, U5.1, U6.2, U6.11
3.3V3: C4.1, D8.A, I2C3.2, J25.2, J26.2, J27.2, J31.2, LS4.+, R24.2, R25.2, R26.2, U7.1, U8.2, U8.11
3.3V4: C5.1, D10.A, I2C4.2, J33.2, J34.2, J35.2, J39.2, LS5.+, R31.2, R32.2, R33.2, U9.1, U10.2, U10.11
3.3V5: C6.1, D12.A, I2C5.2, J41.2, J42.2, J43.2, J47.2, LS6.+, R38.2, R39.2, R40.2, U11.1, U12.2, U12.11
3.3V6: C7.1, D14.A, I2C6.2, J49.2, J50.2, J51.2, J55.2, LS7.+, R45.2, R46.2, R47.2, U13.1, U14.2, U14.11
3.3V7: C8.1, D16.A, I2C7.2, J57.2, J58.2, J59.2, J63.2, LS8.+, R52.2, R53.2, R54.2, U15.1, U16.2, U16.11
3.3V8: C9.1, D18.A, I2C8.2, J65.2, J66.2, J67.2, J71.2, LS9.+, R59.2, R60.2, R61.2, U17.1, U18.2, U18.11
!INT: J5.1, JP8.1, U1.10
!INT1: J12.1, JP17.1, U3.10
!INT2: J20.1, JP26.1, U5.10
!INT3: J28.1, JP35.1, U7.10
!INT4: J36.1, JP44.1, U9.10
!INT5: J44.1, JP53.1, U11.10
!INT6: J52.1, JP62.1, U13.10
!INT7: J60.1, JP71.1, U15.10
!INT8: J68.1, JP80.1, U17.10
!RST: J7.1, J8.5, R2.1, U1.4
!RST1: J15.5, J16.1, R12.1, U3.4
!RST2: J23.5, J24.1, R19.1, U5.4
!RST3: J31.5, J32.1, R26.1, U7.4
!RST4: J39.5, J40.1, R33.1, U9.4
!RST5: J47.5, J48.1, R40.1, U11.4
!RST6: J55.5, J56.1, R47.1, U13.4
!RST7: J63.5, J64.1, R54.1, U15.4
!RST8: J71.5, J72.1, R61.1, U17.4
ANT1: J1.1, U2.3
ANT2: J6.1, U2.4
ANT3: J13.1, U4.3
ANT4: J14.1, U4.4
ANT5: J21.1, U6.3
ANT6: J22.1, U6.4
ANT7: J29.1, U8.3
ANT8: J30.1, U8.4
ANT9: J37.1, U10.3
ANT10: J38.1, U10.4
ANT11: J45.1, U12.3
ANT12: J46.1, U12.4
ANT13: J53.1, U14.3
ANT14: J54.1, U14.4
ANT15: J61.1, U16.3
ANT16: J62.1, U16.4
ANT17: J69.1, U18.3
ANT18: J70.1, U18.4
DATA_UART: U1.11, U2.9
DATA_UART1: U3.11, U4.9
DATA_UART2: U5.11, U6.9
DATA_UART3: U7.11, U8.9
DATA_UART4: U9.11, U10.9
DATA_UART5: U11.11, U12.9
DATA_UART6: U13.11, U14.9
DATA_UART7: U15.11, U16.9
DATA_UART8: U17.11, U18.9
GND: C1.2, D1.C, J2.1, J3.1, J4.1, J8.6, JP7.1, Q1.2, U1.14, U2.1, U2.7
GND1: C2.2, D3.C, J9.1, J10.1, J11.1, J15.6, JP16.1, Q2.2, U3.14, U4.1, U4.7
GND2: C3.2, D5.C, J17.1, J18.1, J19.1, J23.6, JP25.1, Q3.2, U5.14, U6.1, U6.7
GND3: C4.2, D7.C, J25.1, J26.1, J27.1, J31.6, JP34.1, Q4.2, U7.14, U8.1, U8.7
GND4: C5.2, D9.C, J33.1, J34.1, J35.1, J39.6, JP43.1, Q5.2, U9.14, U10.1, U10.7
GND5: C6.2, D11.C, J41.1, J42.1, J43.1, J47.6, JP52.1, Q6.2, U11.14, U12.1, U12.7
GND6: C7.2, D13.C, J49.1, J50.1, J51.1, J55.6, JP61.1, Q7.2, U13.14, U14.1, U14.7
GND7: C8.2, D15.C, J57.1, J58.1, J59.1, J63.6, JP70.1, Q8.2, U15.14, U16.1, U16.7
GND8: C9.2, D17.C, J65.1, J66.1, J67.1, J71.6, JP79.1, Q9.2, U17.14, U18.1, U18.7
LED_BUZZ: R7.2, U2.10
LED_BUZZ1: R13.2, U4.10
LED_BUZZ2: R20.2, U6.10
LED_BUZZ3: R27.2, U8.10
LED_BUZZ4: R34.2, U10.10
LED_BUZZ5: R41.2, U12.10
LED_BUZZ6: R48.2, U14.10
LED_BUZZ7: R55.2, U16.10
LED_BUZZ8: R62.2, U18.10
MISO: J8.1, U1.8
MISO1: J15.1, U3.8
MISO2: J23.1, U5.8
MISO3: J31.1, U7.8
MISO4: J39.1, U9.8
MISO5: J47.1, U11.8
MISO6: J55.1, U13.8
MISO7: J63.1, U15.8
MISO8: J71.1, U17.8
unnamed: I2C.1, R5.2
unnamed: I2C.3, R4.2
unnamed: D1.A, R3.1
unnamed: JP8.2, R1.1
unnamed: D2.C, R8.2
unnamed: JP7.2, U1.13
unnamed: Q1.1, R7.1
unnamed: JP9.1, Q1.3, R8.1
unnamed: JP9.2, LS1.-
unnamed: I2C1.1, R9.2
unnamed: D3.A, R11.1
unnamed: JP16.2, U3.13
unnamed: I2C1.3, R6.2
unnamed: JP17.2, R10.1
unnamed: Q2.1, R13.1
unnamed: JP18.1, Q2.3, R14.1
unnamed: D4.C, R14.2
unnamed: JP18.2, LS2.-
unnamed: I2C2.1, R16.2
unnamed: D5.A, R18.1
unnamed: JP25.2, U5.13
unnamed: I2C2.3, R15.2
unnamed: JP26.2, R17.1
unnamed: Q3.1, R20.1
unnamed: JP27.1, Q3.3, R21.1
unnamed: D6.C, R21.2
unnamed: JP27.2, LS3.-
unnamed: I2C3.1, R23.2
unnamed: D7.A, R25.1
unnamed: JP34.2, U7.13
unnamed: I2C3.3, R22.2
unnamed: JP35.2, R24.1
unnamed: Q4.1, R27.1
unnamed: JP36.1, Q4.3, R28.1
unnamed: D8.C, R28.2
unnamed: JP36.2, LS4.-
unnamed: I2C4.1, R30.2
unnamed: D9.A, R32.1
unnamed: JP43.2, U9.13
unnamed: I2C4.3, R29.2
unnamed: JP44.2, R31.1
unnamed: Q5.1, R34.1
unnamed: JP45.1, Q5.3, R35.1
unnamed: D10.C, R35.2
unnamed: JP45.2, LS5.-
unnamed: I2C5.1, R37.2
unnamed: D11.A, R39.1
unnamed: JP52.2, U11.13
unnamed: I2C5.3, R36.2
unnamed: JP53.2, R38.1
unnamed: Q6.1, R41.1
unnamed: JP54.1, Q6.3, R42.1
unnamed: D12.C, R42.2
unnamed: JP54.2, LS6.-
unnamed: I2C6.1, R44.2
unnamed: D13.A, R46.1
unnamed: JP61.2, U13.13
unnamed: I2C6.3, R43.2
unnamed: JP62.2, R45.1
unnamed: Q7.1, R48.1
unnamed: JP63.1, Q7.3, R49.1
unnamed: D14.C, R49.2
unnamed: JP63.2, LS7.-
unnamed: I2C7.1, R51.2
unnamed: D15.A, R53.1
unnamed: JP70.2, U15.13
unnamed: I2C7.3, R50.2
unnamed: JP71.2, R52.1
unnamed: Q8.1, R55.1
unnamed: JP72.1, Q8.3, R56.1
unnamed: D16.C, R56.2
unnamed: JP72.2, LS8.-
unnamed: I2C8.1, R58.2
unnamed: D17.A, R60.1
unnamed: JP79.2, U17.13
unnamed: I2C8.3, R57.2
unnamed: JP80.2, R59.1
unnamed: Q9.1, R62.1
unnamed: JP81.1, Q9.3, R63.1
unnamed: D18.C, R63.2
unnamed: JP81.2, LS9.-
SCL/SCK: J2.4, J3.4, J4.4, J8.3, R5.1, U1.9
SCL/SCK1: J9.4, J10.4, J11.4, J15.3, R9.1, U3.9
SCL/SCK2: J17.4, J18.4, J19.4, J23.3, R16.1, U5.9
SCL/SCK3: J25.4, J26.4, J27.4, J31.3, R23.1, U7.9
SCL/SCK4: J33.4, J34.4, J35.4, J39.3, R30.1, U9.9
SCL/SCK5: J41.4, J42.4, J43.4, J47.3, R37.1, U11.9
SCL/SCK6: J49.4, J50.4, J51.4, J55.3, R44.1, U13.9
SCL/SCK7: J57.4, J58.4, J59.4, J63.3, R51.1, U15.9
SCL/SCK8: J65.4, J66.4, J67.4, J71.3, R58.1, U17.9
SDA/MOSI: J2.3, J3.3, J4.3, J8.4, R4.1, U1.7
SDA/MOSI1: J9.3, J10.3, J11.3, J15.4, R6.1, U3.7
SDA/MOSI2: J17.3, J18.3, J19.3, J23.4, R15.1, U5.7
SDA/MOSI3: J25.3, J26.3, J27.3, J31.4, R22.1, U7.7
SDA/MOSI4: J33.3, J34.3, J35.3, J39.4, R29.1, U9.7
SDA/MOSI5: J41.3, J42.3, J43.3, J47.4, R36.1, U11.7
SDA/MOSI6: J49.3, J50.3, J51.3, J55.4, R43.1, U13.7
SDA/MOSI7: J57.3, J58.3, J59.3, J63.4, R50.1, U15.7
SDA/MOSI8: J65.3, J66.3, J67.3, J71.4, R57.1, U17.7
TAG_IN_RANGE: U1.5, U2.6
TAG_IN_RANGE1: U3.5, U4.6
TAG_IN_RANGE2: U5.5, U6.6
TAG_IN_RANGE3: U7.5, U8.6
TAG_IN_RANGE4: U9.5, U10.6
TAG_IN_RANGE5: U11.5, U12.6
TAG_IN_RANGE6: U13.5, U14.6
TAG_IN_RANGE7: U15.5, U16.6
TAG_IN_RANGE8: U17.5, U18.6

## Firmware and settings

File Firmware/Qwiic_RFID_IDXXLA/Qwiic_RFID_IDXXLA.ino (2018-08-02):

/*
  An I2C based KeyPad
  By: Elias Santistevan
  SparkFun Electronics
  Date: 2018
  License: This code is public domain but you buy me a beer if you use this and we meet someday (Beerware license).

  Feel like supporting our work? Buy a board from SparkFun!
	<Product Page Here>

  To install support for ATtiny84 in Arduino IDE: https://github.com/SpenceKonde/ATTinyCore/blob/master/Installation.md
  This core is installed from the Board Manager menu
  This core has built in support for I2C S/M and serial
  If you have Dave Mellis' ATtiny installed you may need to remove it from \Users\xx\AppData\Local\Arduino15\Packages

  To support 400kHz I2C communication reliably ATtiny84 needs to run at 8MHz. This requires user to
  click on 'Burn Bootloader' before code is loaded.
*/

#include <Wire.h>

#include <EEPROM.h>

#include <SoftwareSerial.h>

#include <avr/sleep.h>
#include <avr/power.h> 

#define LOCATION_I2C_ADDRESS 0x01 //Location in EEPROM where the I2C address is stored
#define I2C_ADDRESS_DEFAULT 125 //0x7D
#define I2C_ADDRESS_NO_JUMPER 124 //0x7C

#define COMMAND_CHANGE_ADDRESS 0xC7

volatile byte setting_i2c_address = I2C_ADDRESS_DEFAULT; 

volatile byte responseSize = 10; 
//6 byte ID, followed by 4 bytes of time used to pass data back to master
byte responseBuffer[10]; 

//This struct keeps a record of any tag 'events' i.e. reads. 
//This includes the 10 byte Ascii tag ID, 2 byte Checksum, and the 4 other bytes listed below.
#define TAG_ID_SIZE 16 
#define MAX_TAG_STORAGE 20 //How many tags will be held at a time before the first is overwritten.
struct {
  byte tagID[6]; //The Uniqe identifier of the RFID tag, converted from ASCII to HEX will be six bytes in size.
  unsigned long tagTime; //When was the RFID tag sensed?
} tagEvent[MAX_TAG_STORAGE];

volatile byte newestTag = 0;
volatile byte oldestTag = 0;

const byte addrPin = 0; 
const byte interruptPin = 3; //Pin goes low when a tag event is available
const byte resetPin = 11; 

const byte rxPin = 2; 
const byte txPin = 1; //TX Pin is unconnected, unused, and unnecessary except for Software Serial declaration.

SoftwareSerial atSerial = SoftwareSerial(rxPin, txPin); 

const byte startByte = 0x2; //Beginning Transmission Hex value 
const byte endByte = 0x3; //Ending Transmission Hex value
const byte cRHex = 0xD; //Carriage Return Hex
const byte lFHex = 0xA; //Line Follower Hex 

byte tempInc[TAG_ID_SIZE]; 
byte tempTagID[6];

void setup(void)
{
  pinMode(addrPin, INPUT_PULLUP); //Default HIGH = 0x7D or 125
  pinMode(interruptPin, OUTPUT); //Tied high and goes low when an RFID has been scanned.

  pinMode(rxPin, INPUT); 
  pinMode(txPin, OUTPUT); 
	atSerial.begin(9600); //Baud requirement for the ID Module

  //Disable ADC
  ADCSRA = 0;
  //Disble Brown-Out Detect
  MCUCR = bit (BODS) | bit (BODSE);
  MCUCR = bit (BODS);

  //Power down various bits of hardware to lower power usage
  //set_sleep_mode(SLEEP_MODE_PWR_DOWN);
  set_sleep_mode(SLEEP_MODE_IDLE);
  sleep_enable();

  readSystemSettings(); //Load all system settings from EEPROM

  startI2C(); //Determine the I2C address we should be using and begin listening on I2C bus
}

void loop(void)
{
  //Waiting for new RFID cards/capsules to be scanned. 
  if( atSerial.available() )
	{
		while( atSerial.available() ) 
		{	
			if( atSerial.read() != startByte ) break; 
			delay(11);//Necessary to not overwhelm the ID-XXLA module baud rate.
			if( getTagID() ) tagEvent[newestTag].tagTime = millis(); //Get the Tag ID, and verify its' contents, then grab time. 
		}
		if( newestTag++ == MAX_TAG_STORAGE ) newestTag = 0; 
	}

  //Set interrupt pin as needed
  if(newestTag != oldestTag	)
    digitalWrite(interruptPin, LOW); //We have tags on the stack!
  else
    digitalWrite(interruptPin, HIGH); //No tag events to report

  sleep_mode(); //Stop everything and go to sleep. Wake up if I2C event occurs.
}

// We want to convert the tag from it's Ascii representation of a HEX value from the module 
// (12 bytes) to the actual HEX value (6 bytes). The Ascii value is saved into a temporary array 
// and the individual elements of the temporary array are passed to another function where they 
// are converted to the decimal equivalent values and saved into another temporaray array. The value
// is validated and then passed into the final array ready to be sent on the I2C bus.
bool getTagID() 
{
	int j = 0; 
	for( int i = 0; i < TAG_ID_SIZE - 1 ; i ++ ) //TAG_ID_SIZE IS 16, but an index is numerically one less (0-15).
	{
		tempInc[i] = atSerial.read(); 	
		delay(11); //The delay keeps the read commands from outpacing the baud rate of 9600.
	}
	for( int i = 0; i < TAG_ID_SIZE - 1; i ++ ) 
	{
		if( i % 2 == 0 && i !=0 ) j++; 
		if( tempInc[i] == endByte ) break;
		else if( i > 10 && (tempInc[i] == cRHex || tempInc[i] == lFHex)) continue; //Not part of the TAG ID
		else if( i % 2 == 0 ) tempTagID[j] = convertAscii(tempInc[i]) << 4; //MSB
		else ( tempTagID[j] |= convertAscii(tempInc[i]) );//LSB
	}
	j=0;

	if( checkSum(tempTagID) )
	{
		for( int i = 0; i < 6; i++ )
		{
			tagEvent[newestTag].tagID[i] = tempTagID[i];
		}
		return true; 
	} 
	else return false; 
}

// Changes Ascii Values to their decimal representation by subtracting a fixed
// number, best understood by taking a look at an Ascii table. For example: we're 
// changing an Ascii zero, to an actual zero: ASCII "0" = 48 decimal.
byte convertAscii(byte asciiVal)
{
	if( asciiVal >= '0' && asciiVal <= '9' ) return asciiVal -= 48; 
	else if( asciiVal >= 'A' && asciiVal <= 'F' ) return asciiVal -= 55; 
}

//Double checking checksum value given by the tag module just in case something went wrong along the way.
bool checkSum(byte* uncheckedTag)
{
	byte exOr = uncheckedTag[0]; 
	for( int i = 1; i < 5 ; i ++)
	{
		exOr ^= uncheckedTag[i];
	}
	if( exOr == uncheckedTag[5] ) return true; 
	else return false;
}


void receiveEvent(int numberOfBytesReceived)
{
  while (Wire.available())
  {
    //Record bytes to local array
    byte incoming = Wire.read();

    if (incoming == COMMAND_CHANGE_ADDRESS) //Set new I2C address
    {
      if (Wire.available())
      {
        setting_i2c_address = Wire.read();

        //Error check
        if (setting_i2c_address < 0x08 || setting_i2c_address > 0x77)
          continue; //Command failed. This address is out of bounds.

        EEPROM.write(LOCATION_I2C_ADDRESS, setting_i2c_address);

        //Our I2C address may have changed because of user's command
        startI2C(); //Determine the I2C address we should be using and begin listening on I2C bus
      }
    }
  }
}

//Send back a number of bytes via an array, max is 8 bytes at a time, 6 byte TAG ID and 2 byte time stamp.
//When the RFID module gets a request for data from the user, this function is called as an interrupt.
void requestEvent()
{
  loadNextTagToArray(); //Send response buffer
  for (byte x = 0 ; x < responseSize ; x++)
    Wire.write(responseBuffer[x]);
}

//Take the FIFO button press off the stack and load it into the transmit array
void loadNextTagToArray()
{
  if (oldestTag != newestTag)
  {
		for( int i = 0; i < 6; i ++ )
		{
			responseBuffer[i] = tagEvent[oldestTag].tagID[i];
		}
    unsigned long timeSincePressed = millis() - tagEvent[oldestTag].tagTime;//This is the time since last scan.
    responseBuffer[6] = timeSincePressed >> 24; //MSB
    responseBuffer[7] = timeSincePressed >> 16; 
    responseBuffer[8] = timeSincePressed >> 8;
    responseBuffer[9] = timeSincePressed; //LSB
    if (oldestTag++ == MAX_TAG_STORAGE) oldestTag = 0;
  }
  else
  {
    //No new ID's. 
		for( int i = 0; i < 8; i++ )
		{
			responseBuffer[i] = 0; 
		}
  }
}

//Reads the current system settings from EEPROM
//If anything looks weird, reset setting to default value
void readSystemSettings(void)
{
  //Read what I2C address we should use
  setting_i2c_address = EEPROM.read(LOCATION_I2C_ADDRESS);
  if (setting_i2c_address == 255)
  {
    setting_i2c_address = I2C_ADDRESS_DEFAULT; //By default, we listen for I2C_ADDRESS_DEFAULT
    EEPROM.write(LOCATION_I2C_ADDRESS, setting_i2c_address);
  }
}

//Begin listening on I2C bus as I2C slave using the global variable setting_i2c_address
void startI2C()
{
  Wire.end(); //Before we can change addresses we need to stop
  
  if (digitalRead(addrPin) == HIGH) //Default is HIGH, the jumper is closed with paste in production
    Wire.begin(setting_i2c_address); //Start I2C and answer calls using address from EEPROM
  else
    Wire.begin(I2C_ADDRESS_NO_JUMPER); //Force address to I2C_ADDRESS_NO_JUMPER if user has opened the solder jumper

  //The connections to the interrupts are severed when a Wire.begin occurs. So re-declare them.
  Wire.onReceive(receiveEvent);
  Wire.onRequest(requestEvent);
}

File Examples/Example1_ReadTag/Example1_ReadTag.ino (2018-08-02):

/*
	Qwiic RFID board fot the ID-XXLA Modules
	By: Elias Santistevan
	Sparkfun Electronics
	Date: August 2nd, 2018
	License: This code is public domain but if you use this and we meet someday, get me a beer! 

	Feel like supporting our work? Buy a board from Sparkfun!
	https://www.sparkfun.com/products/14867

	This example will do one thing for you: It will give the RFID tag's ID of the first tag scanned. 
*/

#include <Wire.h> 

#define RFID_ADDR 0x7D //0x7D is the default address, 0x7C if you close the address jumper.

byte tagID[6]; //Length of the tag is 5 bytes long followed by 1 byte of checksum.

//We'll use a pin attached to the interrupt line to initiate the check for the RFID tag ID. 
//Feel free to remove it and do a manual check.
const int eventPin = 8;  

void setup()
{
	Wire.begin(); 
	Serial.begin(9600); 
	Serial.println("Waiting for interrupt to fire which indicates a tag has been read!"); 
	pinMode(eventPin, INPUT_PULLUP);//Our pin is active low so let's put it in a known high state.
}
void loop()
{
	if( digitalRead(eventPin) == LOW ) checkTagID();
	delay(250);//slow it down
}

//20 tags can be stored by the product at a time, the first one to be scanned is the first one
//to be pulled from the tag stack. If the tag reads '000000' or the interrupt line never went low
//then there are no new tags waiting to be read. 
void checkTagID()
{	
	Serial.print("RFID Tag ID: "); 
	Wire.requestFrom((uint8_t)RFID_ADDR, (uint8_t)6); 
	for( int x = 0; x < 6; x++ ) 
		tagID[x] = Wire.read(); 
	for( int x = 0; x < 6; x++ ) 
		Serial.print(tagID[x], HEX); 
	Serial.println(); 
}

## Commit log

2018-06-26 Schematic organization
    [Qwiic RFID - ID12LA.brd, Qwiic RFID - ID12LA.sch]
2018-06-26 Moved to double sided to decrease size of product
    Buzzer, LED, and RFID connector live on top.
    [Qwiic RFID - ID12LA.brd, Qwiic RFID - ID12LA.sch]
2018-06-26 Renamed to incorporate all possible RFID modules
    [Qwiic RFID - IDXXLA.brd, Qwiic RFID - IDXXLA.sch]
2018-06-26 More compact
    Shrunk 10 mil, beefed up 3.3V lines to 10 mil
    [Qwiic RFID - IDXXLA.brd, Qwiic RFID - IDXXLA.sch]
2018-06-27 5 mil smaller
    Moved power LED around, squished the PCB a little more.
    [Qwiic RFID - IDXXLA.brd, Qwiic RFID - IDXXLA.sch]
2018-06-27 Moved RST clost to INT PTH, better routing
    [Qwiic RFID - IDXXLA.brd, Qwiic RFID - IDXXLA.sch]
2018-06-27 Production Panel 3x3
    [Qwiic RFID - IDXXLA-Panel.GBL, Qwiic RFID - IDXXLA-Panel.GBO, Qwiic RFID - IDXXLA-Panel.GBP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]
2018-06-29 Initial Code Commit
    [Qwiic RFID - IDXXLA.brd]
2018-07-12 Firmware almost finalized, I2C data lines and UART lines fixed on board
    [Qwiic RFID - IDXXLA.brd, Qwiic RFID - IDXXLA.sch]
2018-07-13 Minor changes to traces
    [Qwiic RFID - IDXXLA.brd, Qwiic RFID - IDXXLA.sch]
2018-07-13 Panel for x02
    [Qwiic RFID - IDXXLA-Panel.brd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]
2018-07-16 Fixed DRC erros added latest panel for x02
    [Qwiic RFID - IDXXLA-Panel.brd, Qwiic RFID - IDXXLA.brd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]
2018-08-02 Cleanup and ReadMe
    [Qwiic RFID - IDXXLA.brd, Qwiic RFID - IDXXLA.sch]
2018-11-09 Jig for testing/programming
    [Qwiic RFID - IDXXLA-BottomJig.brd, Qwiic RFID - IDXXLA-BottomJig.sch, Qwiic RFID - IDXXLA-MiddleJig.brd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]

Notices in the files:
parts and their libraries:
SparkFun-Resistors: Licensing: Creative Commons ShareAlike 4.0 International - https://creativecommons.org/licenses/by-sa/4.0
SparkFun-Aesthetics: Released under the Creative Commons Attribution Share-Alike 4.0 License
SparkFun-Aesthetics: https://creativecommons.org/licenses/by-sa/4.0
